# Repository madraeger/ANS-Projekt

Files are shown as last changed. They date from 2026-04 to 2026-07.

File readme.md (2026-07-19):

# FM-VCO

Dieses Repository enthält die Entwicklung, Simulation und praktische Umsetzung eines spannungsgesteuerten Oszillators für einen Frequenzmodulator.

Der VCO wird in **KiCad** aufgebaut und mit **ngspice** simuliert. Anschließend soll die Schaltung auf einer Platine umgesetzt und messtechnisch untersucht werden.

## Kundenanforderungen

Für den Frequenzmodulator wurden folgende Anforderungen vorgegeben:

- Mittenfrequenz von **5,5 MHz**
- Eingangssignal von **0 V**
- lineare Frequenzänderung von **±0,5 MHz**
- nutzbarer Frequenzbereich von **5 MHz bis 6 MHz**
- möglichst geringe nichtlineare Verzerrungen
- robuste und übersichtliche Platine für den Einsatz im Unterricht
- Verwendung möglichst großer und gut handhabbarer Bauteile
- integrierter Spannungsteiler zur Einstellung des Arbeitspunktes
- Ein- und Ausgang über BNC-Buchsen
- Ausgangswiderstand von **50 Ω**
- Korrektur einer Frequenzdrift über eine einstellbare Gleichspannung
- Aufnahme der Frequenzkennlinie mithilfe einer Gleichspannung
- möglichst kurzschlusssicherer Ausgang

## Grundlagen und Aufbau des VCOs

### Vom Schwingkreis zum Oszillator

Die Grundlage des VCOs bildet ein LC-Schwingkreis aus Induktivitäten und Kapazitäten. Im Schwingkreis wird Energie periodisch zwischen dem magnetischen Feld der Induktivitäten und dem elektrischen Feld der Kapazitäten ausgetauscht.

Die Resonanzfrequenz kann näherungsweise mit

$$
f_0 \approx \frac{1}{2\pi\sqrt{L_\text{}C_\text{}}}
$$

beschrieben werden.

Dabei sind:

- $L_\text{}$ die wirksame Induktivität des Schwingkreises
- $C_\text{}$ die gesamte wirksame Kapazität einschließlich parasitärer Kapazitäten

Ein realer LC-Schwingkreis besitzt Verluste, beispielsweise durch die Innenwiderstände der Induktivitäten, Leiterbahnen und angeschlossene Messgeräte. Ohne zusätzliche Energiezufuhr würde die Schwingung deshalb mit der Zeit abklingen.

Damit eine dauerhafte Schwingung entsteht, muss eine aktive Schaltung die Verluste des Schwingkreises ausgleichen. Dazu wird ein Teil des Ausgangssignals phasenrichtig zurückgeführt und verstärkt. Beim Einschalten reichen bereits kleine Störungen und das elektrische Rauschen aus, um eine Schwingung anzuregen. Die Frequenzanteile in der Nähe der Resonanzfrequenz werden anschließend durch die Rückkopplung verstärkt.

Für das Anschwingen muss die Schleifenverstärkung zunächst ausreichend groß sein. Im eingeschwungenen Zustand stellt sich die Amplitude so ein, dass die zugeführte Energie den Verlusten des Schwingkreises entspricht.

### Aufbau des VCOs

Der verwendete VCO besteht grundsätzlich aus einem differentiellen LC-Schwingkreis, einem gekreuzt gekoppelten MOSFET-Paar und einer Stromquelle.

<p align="center">
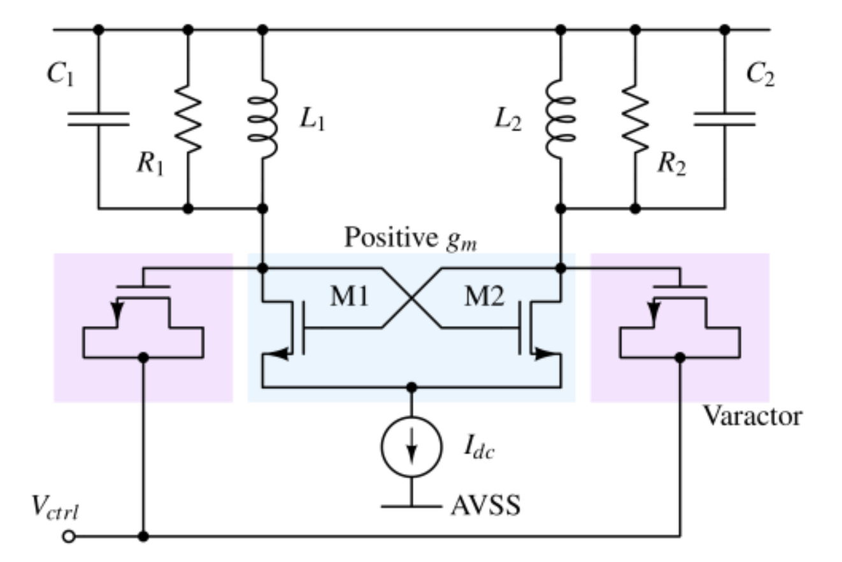
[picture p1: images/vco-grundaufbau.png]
Grundaufbau eines differentiellen LC-VCOs mit Cross-Coupled-MOSFETs
  
</p>

<p align="center">
  <em>
    Vereinfachter Aufbau eines differentiellen LC-VCOs.
    Quelle:
    <a href="https://analogcircuitdesign.com/voltage-controlled-oscillator/">
      Analog Circuit Design
    </a>
  </em>
</p>

Der VCO setzt sich aus folgenden Funktionsgruppen zusammen:

| Funktionsgruppe | Bauteile der Prinzipschaltung | Bauteile der aktuellen Schaltung | Aufgabe |
|---|---|---|---|
| LC-Schwingkreis | `L1`, `L2`, `C1`, `C2` sowie die Verlustwiderstände `R1`, `R2` | `L1`, `L2`, `D1`, `D2` | Festlegung der Resonanzfrequenz |
| Cross-Coupled-Paar | `M1`, `M2` | `Q1`, `Q2` | Ausgleich der Schwingkreisverluste und Aufrechterhaltung der Schwingung |
| Frequenzabstimmung | Varaktordioden und Steuerspannung `Vctrl` | `D1`, `D2` und Abstimmspannung `Vtune` | Veränderung der wirksamen Kapazität und damit der Ausgangsfrequenz |
| Stromquelle | ideale Stromquelle `Idc` | `Q3`, `Q4`, `R4` | Einstellung und Begrenzung des Arbeitspunktstroms |
| Ausgang | einer der beiden Schwingkreisknoten | rechter Schwingkreisknoten | Ausgabe des hochfrequenten Signals |

In der Prinzipschaltung werden die Verluste des LC-Schwingkreises durch die Parallelwiderstände `R1` und `R2` dargestellt. In der realen Schaltung entstehen diese Verluste bereits durch die Innenwiderstände der Spulen, die Varaktordioden, die MOSFETs und die Leiterbahnen. Deshalb wurden keine zusätzlichen Widerstände parallel zum Schwingkreis eingesetzt.

Die Kondensatoren `C1` und `C2` der Prinzipschaltung werden in der aktuellen Schaltung hauptsächlich durch die spannungsabhängigen Kapazitäten der Varaktordioden `D1` und `D2` ersetzt.

Der LC-Schwingkreis bestimmt die Ausgangsfrequenz. Das Cross-Coupled-Transistorpaar führt dem Schwingkreis die durch reale Verluste abgegebene Energie wieder zu. Die Varaktordioden ermöglichen die spannungsabhängige Frequenzeinstellung über `Vtune`.

Als Stromquelle wird ein einfacher NMOS-Stromspiegel verwendet. Dieser stellt den Arbeitspunktstrom für das Cross-Coupled-Transistorpaar bereit.

Die einzelnen Funktionsgruppen werden in den folgenden Abschnitten genauer beschrieben.
### Cross-Coupled-Transistorpaar

Die MOSFETs `Q1` und `Q2` sind über Kreuz miteinander gekoppelt. Das Gate eines Transistors ist jeweils mit dem Drain des anderen Transistors verbunden.

Die beiden Schwingkreisknoten schwingen dadurch näherungsweise gegenphasig. Steigt die Spannung an einem Knoten an, fällt sie am anderen Knoten ab.

Das Transistorpaar erzeugt im Schwingkreis einen negativen differentiellen Widerstand. Dieser wirkt den realen Verlustwiderständen des Schwingkreises entgegen. Sind die Verluste ausreichend kompensiert, kann die Schwingung dauerhaft bestehen bleiben.

### Spannungsabhängige Frequenzabstimmung

Damit aus dem LC-Oszillator ein spannungsgesteuerter Oszillator wird, werden die festen Kapazitäten durch Varaktordioden ersetzt.

Eine Varaktordiode wird in Sperrrichtung betrieben und verhält sich dabei wie ein spannungsabhängiger Kondensator. Die Abstimmspannung `Vtune` verändert die Sperrspannung und damit die Kapazität der Dioden.

Dadurch verändert sich die wirksame Kapazität des Schwingkreises:

$$
V_\text{tune}
\longrightarrow
C_\text{Varaktor}
\longrightarrow
f_\text{out}
$$

In der aktuellen Schaltung nimmt die gemessene Ausgangsfrequenz mit zunehmender Spannung `Vtune` ab. Die genaue Richtung der Frequenzänderung hängt von der Verschaltung der Varaktordioden und den Spannungsverhältnissen innerhalb des Schwingkreises ab.

Für einen möglichst verzerrungsarmen Frequenzmodulator sollte der Zusammenhang zwischen Abstimmspannung und Ausgangsfrequenz im verwendeten Arbeitsbereich möglichst linear sein:

$$
f_\text{out}
\approx
f_\text{Mitte}
+
K_\text{VCO}\cdot\left(V_\text{tune}-V_\text{Mitte}\right)
$$

Dabei beschreibt $K_\text{VCO}$ die Empfindlichkeit des VCOs und wird beispielsweise in `MHz/V` angegeben.

### NMOS-Stromspiegel

Die Stromquelle des VCOs wird als einfacher NMOS-Stromspiegel ausgeführt.

<p align="center">
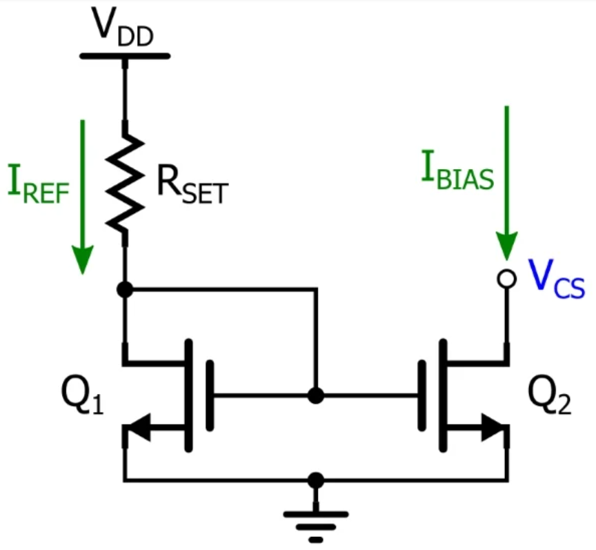
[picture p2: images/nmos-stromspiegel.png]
Einfacher NMOS-Stromspiegel mit Referenzwiderstand
  
</p>

<p align="center">
  <em>
    Prinzip eines einfachen NMOS-Stromspiegels.
    Quelle:
    <a href="https://www.allaboutcircuits.com/technical-articles/the-basic-mosfet-constant-current-source/">
      All About Circuits
    </a>
  </em>
</p>

Der Stromspiegel besteht in der aktuellen Schaltung aus den MOSFETs `Q3` und `Q4` sowie dem Widerstand `R4`.

Bei `Q4` sind Gate und Drain miteinander verbunden. Der Transistor ist damit als Referenztransistor beschaltet. Über den Widerstand `R4` stellt sich ein Referenzstrom ein.

Da die Gates von `Q3` und `Q4` miteinander verbunden sind, liegt an beiden MOSFETs näherungsweise dieselbe Gate-Source-Spannung an. Dadurch übernimmt `Q3` näherungsweise den Strom des Referenzzweigs und stellt den Arbeitspunktstrom für das Cross-Coupled-Transistorpaar bereit.

Die Bauteile der Prinzipschaltung entsprechen in der aktuellen VCO-Schaltung folgenden Bauteilen:

| Prinzipschaltung | Aktuelle Schaltung |
|---|---|
| Referenztransistor `Q1` | `Q4` |
| Ausgangstransistor `Q2` | `Q3` |
| Einstellwiderstand `RSET` | `R4` |
| Referenzstrom `IREF` | Strom durch `R4` und `Q4` |
| Ausgangsstrom `IBIAS` | Arbeitspunktstrom für `Q1` und `Q2` |

Der Referenzstrom kann vereinfacht mit folgender Gleichung abgeschätzt werden:

$$
I_\text{REF}
\approx
\frac{V_\text{DD}-V_\text{GS}}{R_4}
$$

Diese Gleichung ist nur eine Näherung, da die Gate-Source-Spannung `VGS` vom verwendeten MOSFET, vom Strom und von der Temperatur abhängt.

Der Stromspiegel stabilisiert damit den Arbeitspunkt der Schaltung, stellt jedoch keine vollständige automatische Regelung der Ausgangsamplitude dar.

## Verwendete Bauteile

Für den aktuellen Aufbau werden unter anderem folgende Bauteile verwendet:

| Bezeichnung | Bauteil | Funktion | SPICE-Modell / Bibliothek | Datenblatt |
|---|---|---|---|---|
| Q1, Q2 | [`BS170`](https://www.onsemi.com/download/data-sheet/pdf/mmbf170-d.pdf) | Cross-Coupled-Transistorpaar | `elk.lib` |  |
| Q3, Q4 | [`BS170`](https://www.onsemi.com/download/data-sheet/pdf/mmbf170-d.pdf) | NMOS-Stromspiegel | `elk.lib` |  |
| D1, D2 | [`1SV149`](https://www.radiomuseum.co.uk/filter/1SV149.pdf) | Varaktordioden zur Frequenzabstimmung | `BB112.lib` beziehungsweise eigenes `1SV149`-Modell |  |
| L1, L2 | 3,3 µH | Induktiver Teil des Schwingkreises | Standardmodell aus `spice.lib` | – |
| R4 | 51 kΩ | Einstellung des Referenzstroms im realen Aufbau | Standardmodell aus `spice.lib` | – |

Für die MOSFETs wird das Modell des `BS170` aus der Bibliothek `elk.lib` verwendet. Die passiven Bauteile greifen auf die Standardmodelle aus `spice.lib` zurück.

Für die Varaktordioden wurde zunächst das Modell aus `BB112.lib` verwendet, da damit in der Simulation eine deutliche Frequenzänderung erreicht werden konnte. Alternativ wird ein eigenes Modell für die `1SV149` eingesetzt. Das Modell aus `BB112.lib` entspricht dabei nicht exakt der real verbauten `1SV149`, sondern dient lediglich als Näherung ihres kapazitätsabhängigen Verhaltens.

## Aktueller Stand

Der VCO wurde sowohl in **SPICE simuliert** als auch **praktisch aufgebaut**. Der geforderte nutzbare Frequenzbereich von ungefähr **5 MHz bis 6 MHz** wird bereits erreicht.

Die Ausgangsfrequenz wird über die Abstimmspannung `Vtune` eingestellt. Mit steigender Abstimmspannung sinkt die Ausgangsfrequenz. Die aufgenommenen Messwerte zeigen dabei einen nahezu linearen Zusammenhang zwischen `Vtune` und der Ausgangsfrequenz.

### Gemessene f/V-Kennlinie

Die Kennlinie wurde aufgenommen, indem die Gleichspannung `Vtune` schrittweise verändert und die jeweilige Ausgangsfrequenz gemessen wurde.

| `Vtune` in V | Frequenz in MHz |
|---:|---:|
| 5,33 | 6,00 |
| 5,50 | 5,90 |
| 5,63 | 5,83 |
| 5,82 | 5,69 |
| 5,92 | 5,61 |
| 6,06 | 5,52 |
| 6,24 | 5,42 |
| 6,36 | 5,33 |
| 6,54 | 5,21 |
| 6,70 | 5,11 |
| 6,89 | 5,01 |

<p align="center">
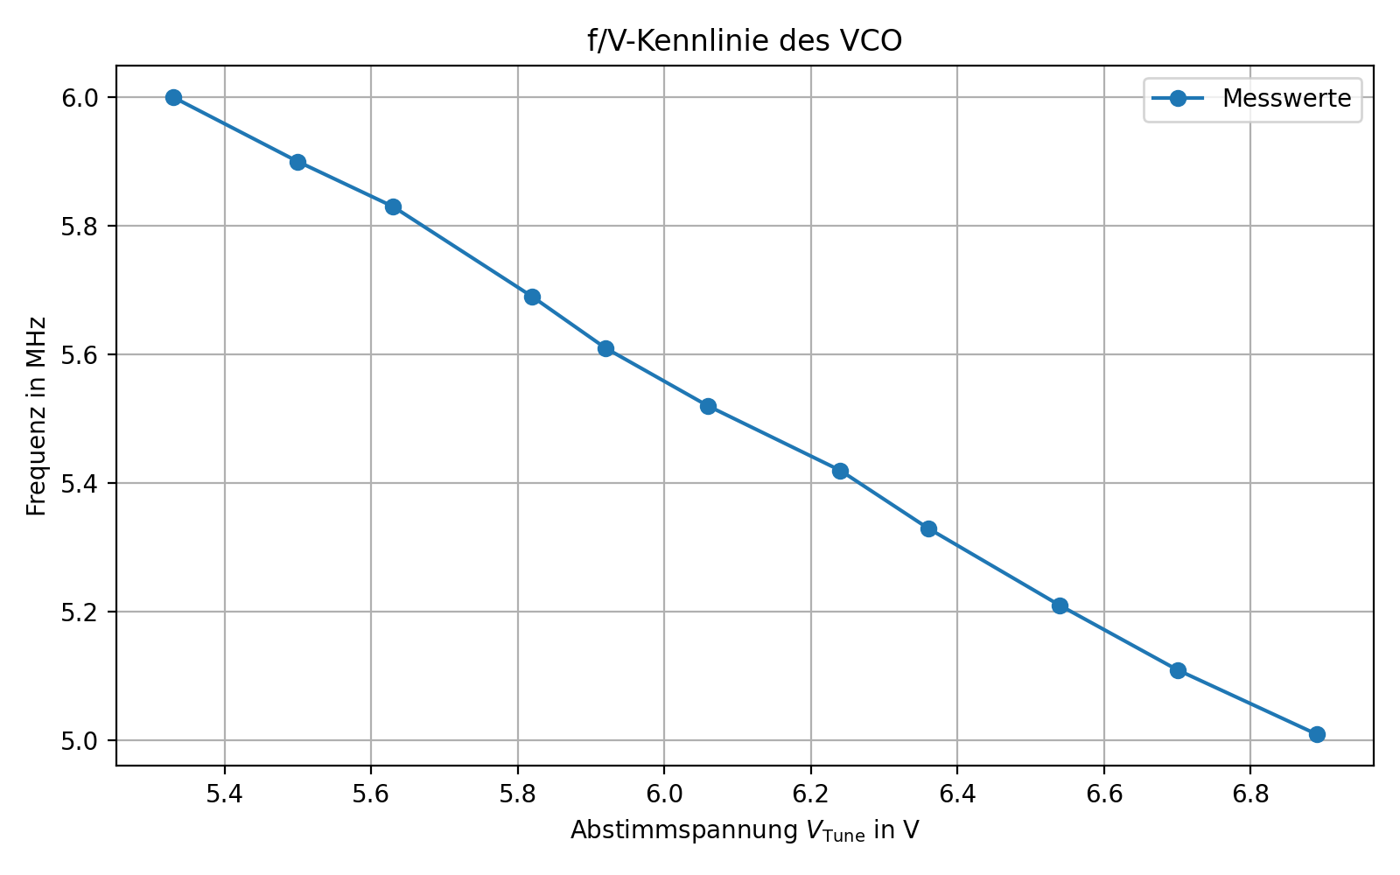
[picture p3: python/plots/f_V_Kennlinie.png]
Gemessene f/V-Kennlinie des VCOs
  
</p>

<p align="center">
  <em>Gemessene Ausgangsfrequenz in Abhängigkeit von der Abstimmspannung Vtune</em>
</p>

Die VCO-Empfindlichkeit beträgt näherungsweise:

$$
K_\text{VCO}
\approx
-0{,}650\,
\frac{\text{MHz}}{\text{V}}
$$

Das negative Vorzeichen bedeutet, dass die Ausgangsfrequenz mit steigender Abstimmspannung abnimmt.

Die Mittenfrequenz von ungefähr **5,5 MHz** wird bei einer Abstimmspannung von etwa **6,1 V** erreicht.

Für den gesamten Frequenzbereich von ungefähr **5 MHz bis 6 MHz** wird eine Spannungsänderung von etwa

$$
\Delta V_\text{tune} = 6{,}89\,\text{V} - 5{,}33\,\text{V} = 1{,}56\,\text{V}
$$

benötigt.

Bezogen auf den Arbeitspunkt bei ungefähr **6,1 V** entspricht dies einem benötigten Spannungshub von ungefähr:

$$
V_\text{tune}
\approx
6{,}1\,\text{V}
\pm
0{,}78\,\text{V}
$$

Der ursprünglich vorgesehene Eingangsspannungsbereich von ungefähr **±0,5 V** reicht daher ohne eine zusätzliche Anpassung nicht für den vollständigen Frequenzbereich aus.

### Gemessene Ausgangssignale

Die folgende Abbildunge zeigt die letzten zwei Perioden des mit dem Oszilloskop aufgenommenen Ausgangssignals.

<p align="center">
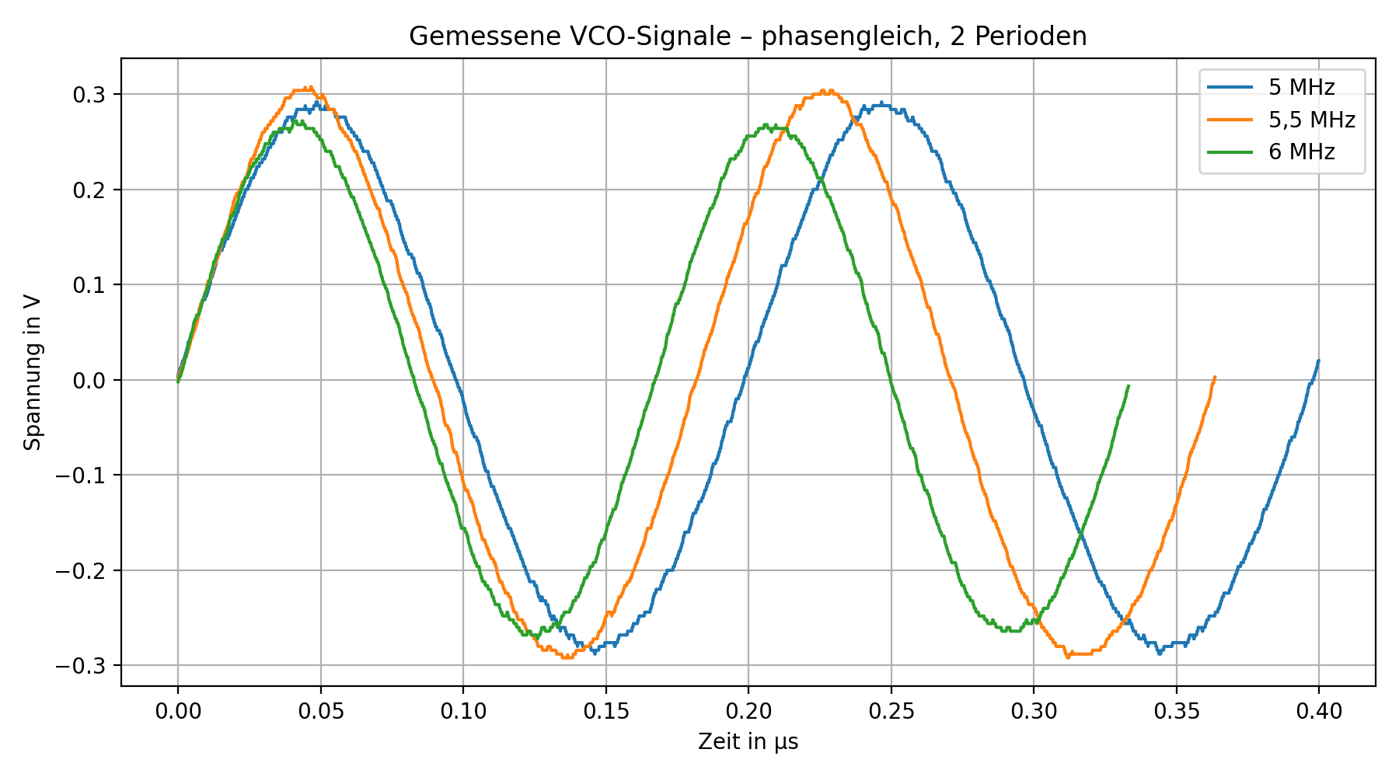
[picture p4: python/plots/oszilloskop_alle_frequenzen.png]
Oszilloskopmessung des Ausgangssignals bei 5 MHz
  
</p>

<p align="center">
  <em>Gemessenes Ausgangssignal bei 5 - 6 MHz</em>
</p>

Die gemessenen Signale besitzen über den untersuchten Frequenzbereich eine weitgehend sinusförmige Signalform.

Die Ausgangsamplitude ist bei **5 MHz** und **5,5 MHz** ähnlich groß. In Richtung **6 MHz** nimmt die Amplitude jedoch sichtbar ab. Die Ursache dafür muss im weiteren Projektverlauf noch untersucht werden.

### Simulation und Vergleich

Für die Frequenzen **5 MHz**, **5,5 MHz** und **6 MHz** wurden die simulierten Ausgangssignale mit den Oszilloskopmessungen verglichen.

<details>
  <summary><strong>Vergleich bei 5 MHz anzeigen</strong></summary>

  #### Vergleich bei 5 MHz

  <p align="center">
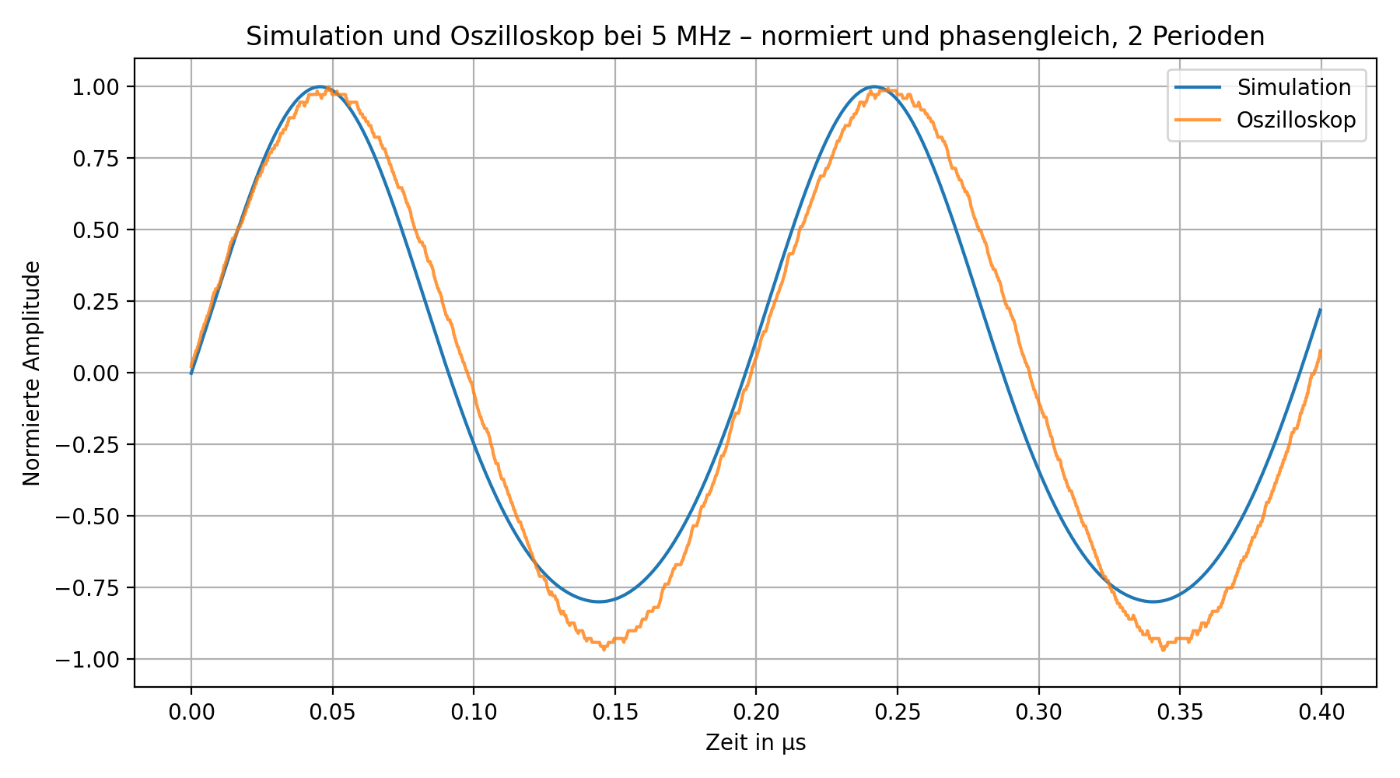
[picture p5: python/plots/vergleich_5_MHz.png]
Vergleich zwischen Simulation und Messung bei 5 MHz
    
  </p>
</details>

<details>
  <summary><strong>Vergleich bei 5,5 MHz anzeigen</strong></summary>

  #### Vergleich bei 5,5 MHz

  <p align="center">
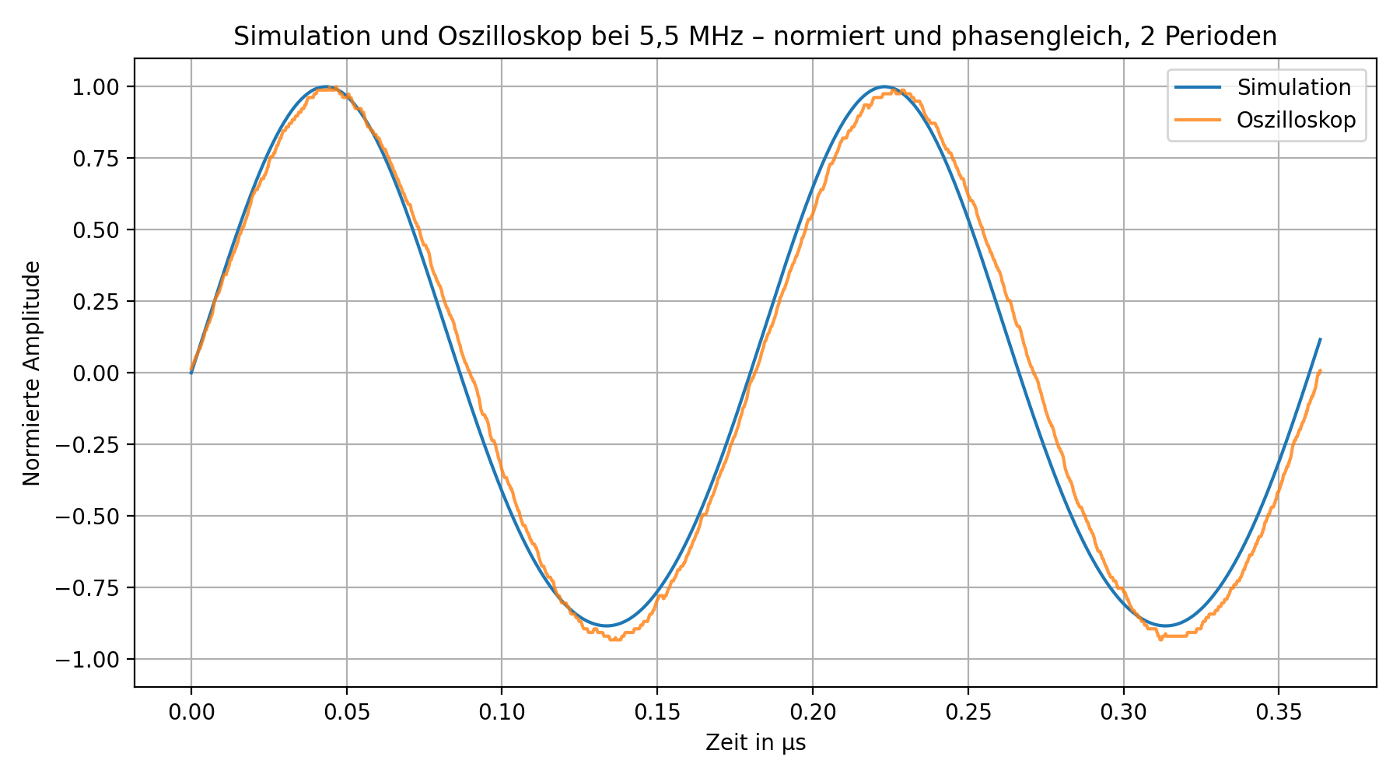
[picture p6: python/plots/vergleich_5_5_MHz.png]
Vergleich zwischen Simulation und Messung bei 5,5 MHz
    
  </p>
</details>

<details>
  <summary><strong>Vergleich bei 6 MHz anzeigen</strong></summary>

  #### Vergleich bei 6 MHz

  <p align="center">
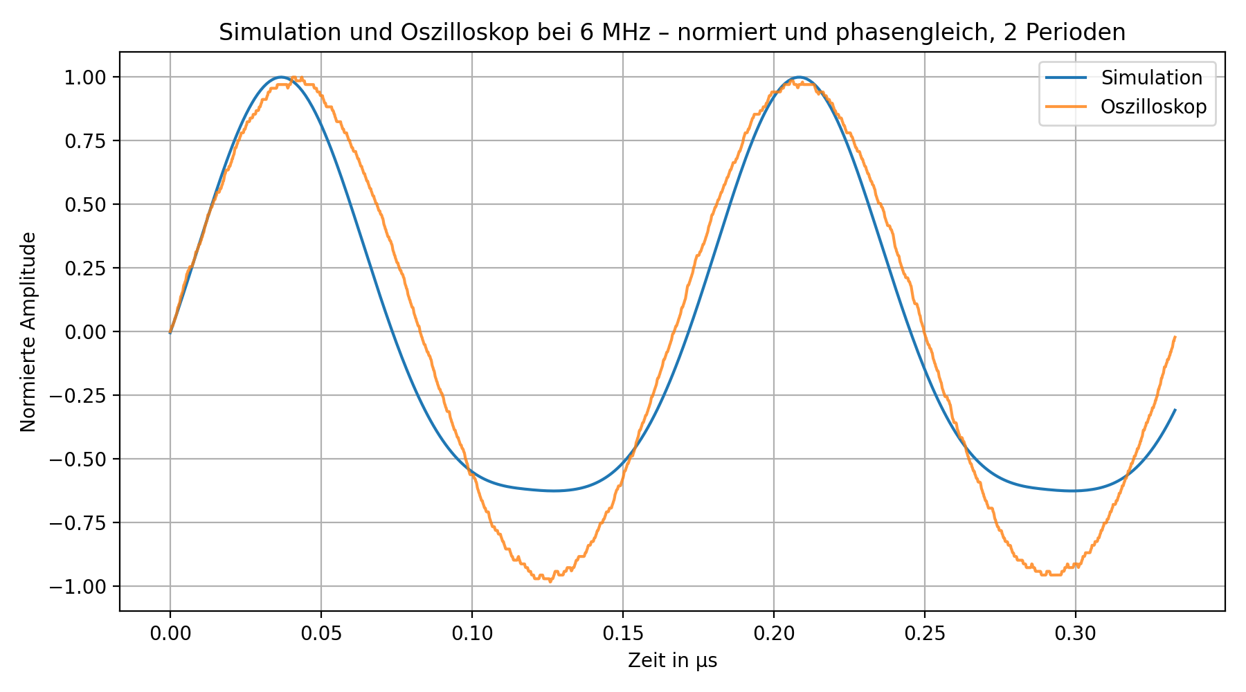
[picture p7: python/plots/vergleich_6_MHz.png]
Vergleich zwischen Simulation und Messung bei 6 MHz
    
  </p>
</details>

Die normierten Vergleichsplots zeigen, dass Simulation und Messung grundsätzlich eine ähnliche periodische Signalform besitzen.

Die Simulation beschreibt damit das grundsätzliche Schwingverhalten, bildet den realen Arbeitspunkt und die tatsächliche Ausgangsamplitude jedoch nur eingeschränkt ab.

### Unterschiede zwischen Simulation und realem Aufbau

Für den NMOS-Stromspiegel werden in der Simulation und im realen Aufbau unterschiedliche Widerstandswerte benötigt.

Im realen Aufbau wird für `R4` ein Widerstand von **51 kΩ** verwendet. Bei größeren Widerständen ist der Strom zu gering, sodass der Oszillator nicht zuverlässig anschwingt.

In der SPICE-Simulation wird dagegen ein größerer Widerstand benötigt, da kleinere Widerstandswerte dort zu stärkeren Verzerrungen des Ausgangssignals führen.

Zusätzlich wurden im realen Aufbau Kondensatoren parallel zur Spannungsversorgung eingesetzt. Diese dienen als Abblock- und Stützkondensatoren und reduzieren hochfrequente Störungen sowie kurzzeitige Spannungsschwankungen.

### Platinenlayout

Eine erste Platine wurde bereits in KiCad erstellt. Das Layout muss jedoch noch an den aktuellen Schaltungsstand angepasst und weiter optimiert werden.

Besonders berücksichtigt werden müssen:

- Platzierung der Abblockkondensatoren nahe an den MOSFETs
- Ein- und Ausgangsanpassung

## Noch nicht vollständig erfüllte Anforderungen

Der geforderte Frequenzbereich von ungefähr **5 MHz bis 6 MHz** und die Mittenfrequenz von ungefähr **5,5 MHz** werden bereits erreicht. Auch die Frequenzkennlinie wurde mithilfe einer veränderlichen Gleichspannung aufgenommen und zeigt im untersuchten Bereich einen nahezu linearen Verlauf.

Folgende Kundenanforderungen sind noch nicht vollständig erfüllt:

- Anpassung des Eingangs von **0 V**
- Umsetzung einer Frequenzänderung von ungefähr **±0,5 MHz** bei einem Eingangssignal von **±0,5 V**
- weitere Verringerung beziehungsweise genaue Bewertung der nichtlinearen Verzerrungen
- Anpassung und Optimierung des bereits erstellten Platinenlayouts
- Realisierung eines Ausgangswiderstands von **50 Ω**
- Umsetzung und Prüfung der Korrektur einer Frequenzdrift über eine einstellbare Gleichspannung
- möglichst kurzschlusssichere Auslegung des Ausgangs
- Aufbau und Prüfung der endgültigen Platine

## Verwendete Software

Für die Entwicklung, Simulation und Versionsverwaltung werden folgende Programme verwendet:

| Software | Verwendung | Download |
|---|---|---|
| KiCad | Erstellung des Schaltplans und des Platinenlayouts |  |
| ngspice | Simulation der Schaltung und Untersuchung des VCO-Verhaltens |  |
| Git | Lokale Versionsverwaltung des Projekts |  |
| GitHub | Speicherung und gemeinsame Bearbeitung des Repositorys |  |

KiCad verwendet für die integrierte SPICE-Simulation ngspice. Abhängig von der KiCad-Installation kann ngspice daher bereits enthalten sein.

## Projekt öffnen

Das Repository kann mit folgendem Befehl geklont werden:

```bash
git clone <URL-DES-REPOSITORY>
```

Der aktuelle Stand des KiCad-Projekts befindet sich im folgenden Unterordner:

```text
kicad/FM-ELK_LC-VCO-V3
```

Anschließend kann die darin enthaltene `.kicad_pro`-Datei mit KiCad geöffnet werden.

Vor der Simulation sollte überprüft werden, ob:

- alle Symbolbibliotheken vorhanden sind
- alle Footprints korrekt zugeordnet sind
- das SPICE-Modell der `1SV149` eingebunden ist
- die Modellpfade in KiCad korrekt eingestellt sind

## Projektteam

<p>
  <a href="https://github.com/madraeger">
    
  </a>
  <a href="https://github.com/ethaniellingkoenig">
    
  </a>
</p>

## Literaturverzeichnis

Die folgenden Quellen wurden für die Grundlagen und die Entwicklung der Schaltung verwendet:

1. [Analog Circuit Design: Voltage Controlled Oscillator – VCO Basics, Operation, Tuning and Use in Communication Circuits](https://analogcircuitdesign.com/voltage-controlled-oscillator/)  
   Grundlagen zu spannungsgesteuerten Oszillatoren, LC-VCOs, Varaktordioden und VCO-Kennlinien.

2. [Electronics Tutorials: LC Oscillator Tutorial and Tuned LC Oscillator Basics](https://www.electronics-tutorials.ws/oscillator/oscillators.html)  
   Grundlagen zu LC-Schwingkreisen, Rückkopplung und den Bedingungen für eine dauerhafte Schwingung.

3. [ElektronikTutor: Frequenzmodulation](https://www.elektroniktutor.de/signalkunde/fm.html)  
   Grundlagen zur Frequenzmodulation, zum Frequenzhub, zum Modulationsindex und zur Bandbreite eines FM-Signals.

4. [All About Circuits: The Basic MOSFET Constant-Current Source](https://www.allaboutcircuits.com/technical-articles/the-basic-mosfet-constant-current-source/)  
   Grundlagen zur MOSFET-Stromquelle und zum Stromspiegel.

Alle Internetquellen wurden zuletzt am **18. Juli 2026** abgerufen.

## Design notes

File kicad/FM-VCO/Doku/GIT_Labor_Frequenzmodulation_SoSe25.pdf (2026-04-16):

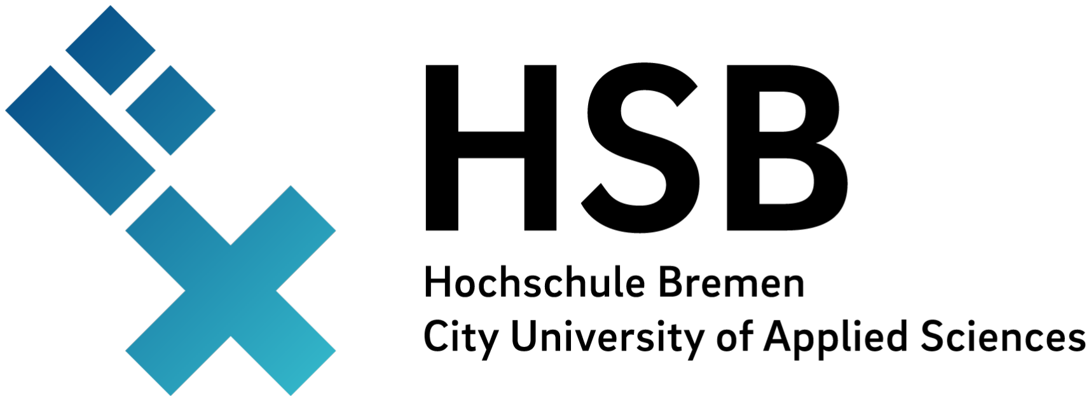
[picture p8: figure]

# Grundlagen der Informationstechnik -Labor-

## Versuch GIT-L 3 Frequenzmodulation

### Prof. Dr.-Ing. Mario Goldenbaum Fakultät für Elektrotechnik und Informatik Hochschule Bremen

Versuch GIT-L 3

## 1 Einleitung

Gegenstand dieses Laborversuchs ist die messtechnische Auseinandersetzung mit der aus der Vorlesung bekannten Frequenzmodulation (FM) bzw. der Winkelmodulation im weiteren Sinne. Mit Hilfe der FM kann ein informationstragendes Signal durch Änderung der Momentanfrequenz eines sinusförmigen Trägers in einen anderen Frequenzbereich umgesetzt werden. Eine Schaltung, die diesem Prinzip folgt und hier näher untersucht werden soll ist am Ende der Versuchsbeschreibung in den Abbildungen 1–3 dargestellt. Den wesentlichen Kern dieser Schaltung bildet ein spannungsgesteuerter Oszillator (LC-Schwingkreis), der mittels eines astabilen Multivibrators rhythmisch angefacht wird.

## 2 Versuchsvorbereitung

Für eine angemessene Vorbereitung auf die Versuchsdurchführung ist es erforderlich, dass Sie die Versuchsbeschreibung aufmerksam lesen und sich hinreichend mit der Funktionsweise der Schaltung in Abb. 1 vertraut machen. Darüber hinaus sollten Sie in der Lage sein, die folgenden Fragen zu beantworten bzw. entsprechende Begriffe zu erörtern.

- Was ist das grundlegende Prinzip der Frequenz- und der Phasenmodulation?
- Wie sehen winkelmodulierte Signale im Zeitbereich typischerweise aus?
- Wie ist der Modulationsindex m definiert und was beschreibt er?
- Wie lässt sich das Frequenzspektrum eines FM-Signals berechnen bei einem sinusförmigen Informationssignal?
- Wie lässt sich der Bandbreitebedarf eines FM-Signals abschätzen?
- Wie hängen die Frequenz- und die Phasenmodulation miteinander zusammen?
- Was versteht man unter Frequency Shift Keying (FSK)?

Fertigen Sie im Anschluss an die Versuchsdurchführung einen Laborbericht an, der neben den Antworten auf diese Fragen eine detaillierte Auseinandersetzung mit den Messaufgaben enthält, gefolgt von einer kritischen Beurteilung der erhaltenen Ergebnisse.

© Prof. Dr.-Ing. Mario Goldenbaum | ver25/1 | 1

Versuch GIT-L 3

## 3 Versuchsdurchführung

### 3.1 Statische Modulationskennlinie

In diesem Versuchsteil soll zunächst die Wirkungsweise der Modulatorschaltung aus Abb.1 näher untersucht werden, indem die Abhängigkeit zwischen dem Ausgang des Modulators (moduliertes Signal) und seinem Eingang (modulierendes Signal) messtechnisch erfasst, ausgewertet und beurteilt wird.

1.1 Ermitteln Sie messtechnisch die statische Modulationskennlinie ω = f(Ue), d.h. die Momentanfrequenz ω = ω(t) der modulierten Ausgangsspannung xFM(t) als Funktion des Augenblickswertes Ue des modulierenden Eingangssignals u(t). Führen Sie dafür den Augenblickswert in Form einer Gleichspannung an den DC-Eingang und variieren diese schrittweise mittels des auf der Platine befindlichen Drehpotentiometers im Bereich von −4 V bis +9 V. Messen Sie für jeden Augenblickswert die Momentanfrequenz am Ausgang des Modulators mit einem Frequenzzähler oder Oszilloskop.

1.2 Stellen Sie die Kennlinie dar und wählen einen Bereich, der Ihnen für einen ordnungsgemäßen Betrieb des Modulators sinnvoll erscheint.

### 3.2 Frequenzspektren harmonischer Modulationssignale

Die folgenden Messaufgaben dienen dazu das frequenzmodulierte Ausgangssignal xFM(t) im Frequenzbereich zu untersuchen und mit den Verläufen zu vergleichen, die man auf Grund theoretischer Überlegungen erwarten würde.

2.1 Für ein sinusförmiges Modulationssignal mit einer Frequenz f1 = 10 kHz sollen frequenzmodulierte Signale mit den Modulationsindizes m = 0,5, m = 2,4 und m = 10 realisiert werden. Bestimmen Sie dafür zunächst die benötigten Frequenzhübe ∆Ω (bzw. ∆F in Hz) und berechnen mit Hilfe der Kennlinie aus 1.1 die einzustellenden Signalamplituden.

Berechnen Sie nun unter Verwendung der in den Abbildungen 4 und 5 dargestellten Besselfunktionen erster Art ν-ter Ordnung für alle drei Fälle die Frequenzspektren. Anschließend bestimmen Sie die Frequenzspektren messtechnisch mit dem Spektrumanalysator. Vergleichen Sie die Messwerte mit Ihren Berechnungen und bestimmen den jeweiligen Bandbreitebedarf der Signale mit der Formel von Carson.

2.2 Wiederholen Sie die vorangegangene Messung für einen Modulationsindex von m = 2,4 bei einer Signalfrequenz von f1 = 20 kHz. Bestimmen Sie dafür die benötigte Signalamplitude des modulierenden Signals und vergleichen das Spektrum mit dem aus 2.1. Wie groß wäre die benötigte Amplitude, wenn es sich um eine Phasenmodulation handeln würde?

© Prof. Dr.-Ing. Mario Goldenbaum | ver25/1 | 2

Versuch GIT-L 3

2.3 Der Frequenzmodulator soll nun als Phasenmodulator betrieben werden. Welcher mathematischen Operation ist dafür das Eingangssignal vor der Einspeisung am Eingang zu unterziehen? Dimensionieren Sie eine entsprechende Schaltung, die diese Operation in einem Frequenzbereich von etwa 10 kHz−20 kHz realisiert. Erzeugen Sie nun mit der modifizierten Schaltung ein phasenmoduliertes Signal für f1 = 20 kHz und m = 2,4 und messen dessen Frequenzspektrum. Vergleichen Sie das Spektrum mit dem zuvor in 2.2 gemessenen Spektrum für die frequenzmodulierte Variante.

### 3.3 Frequenzspektren periodischer Modulationssignale

Im bisherigen Versuchsverlauf haben wir uns ausschließlich mit sinusförmigen Modulationssignalen beschäftigt. In diesem Versuchsteil sollen die Untersuchungen auf andere periodische Signalformen ausgedehnt werden.

3.1 Messen Sie das Frequenzspektrum eines Sinus-, eines Dreieck- und eines Rechtecksignals der Frequenz f1 = 10 kHz und einer Amplitude, die im Falle des Sinussignals zu einem Modulationsindex von m = 10 führt. Vergleichen Sie die Spektren miteinander.

3.2 Realisieren Sie mit einem Rechtecksignal der Frequenz f1 = 10 kHz eine Frequenzumtastung (FSK, Frequency Shift Keying). Bestimmen Sie mit Hilfe der unter 1.1 gemessenen statischen Modulationskennlinie die benötigten Signalamplituden für einen Modulationsindex von m = 0,5 (MSK, Minimum Shift Keying) sowie für m = 1. Wie lassen sich die Spektren erklären?

3.3 Für ein niederfrequentes Dreiecksignal (Wobbelsignal) soll das Spektrum in Abhängigkeit von der Wobbelfrequenz bei einem Wobbelhub von etwa 250 kHz gemessen werden. Messen Sie abschließend das Spektrum eines Sinussignals mit wachsender Signalfrequenz (f1 > 20 kHz), das jeweils zu einem Modulationsindex von m = 10 führt. Woher rühren die Abweichungen vom erwarteten Verlauf bei höheren Frequenzen?

© Prof. Dr.-Ing. Mario Goldenbaum | ver25/1 | 3

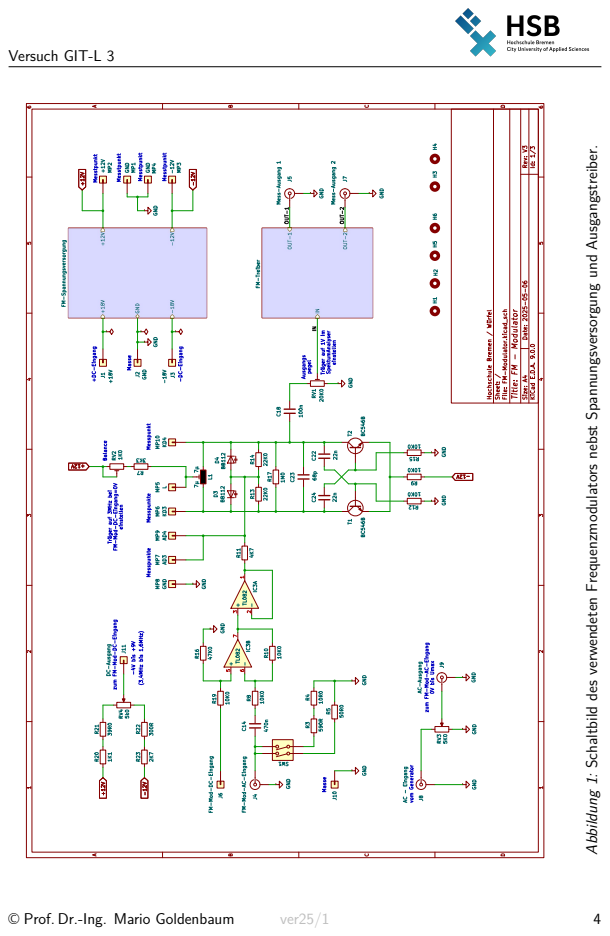
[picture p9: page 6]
Versuch GIT-L 3; © Prof. Dr.-Ing. Mario Goldenbaum; ver25/1

Abbildung 1: Schaltbild des verwendeten Frequenzmodulators nebst Spannungsversorgung und Ausgangstreiber.

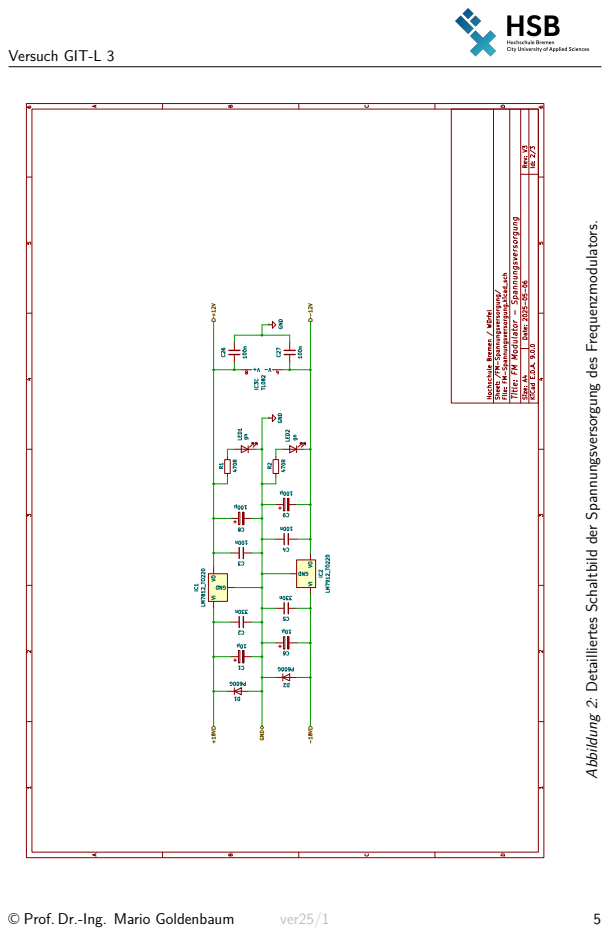
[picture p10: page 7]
Versuch GIT-L 3; © Prof. Dr.-Ing. Mario Goldenbaum; ver25/1

Abbildung 2: Detailliertes Schaltbild der Spannungsversorgung des Frequenzmodulators.

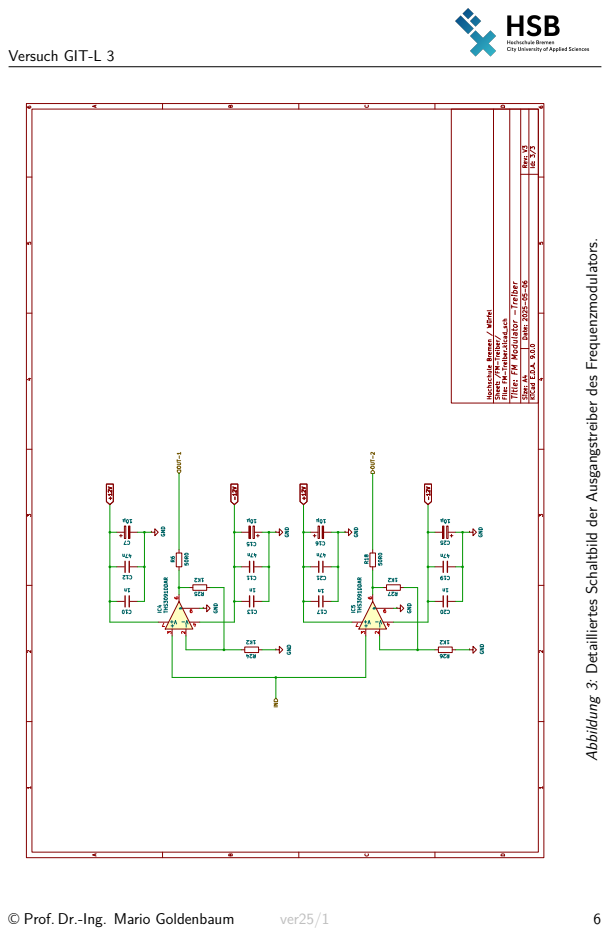
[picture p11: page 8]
Versuch GIT-L 3; © Prof. Dr.-Ing. Mario Goldenbaum; ver25/1

Abbildung 3: Detailliertes Schaltbild der Ausgangstreiber des Frequenzmodulators.

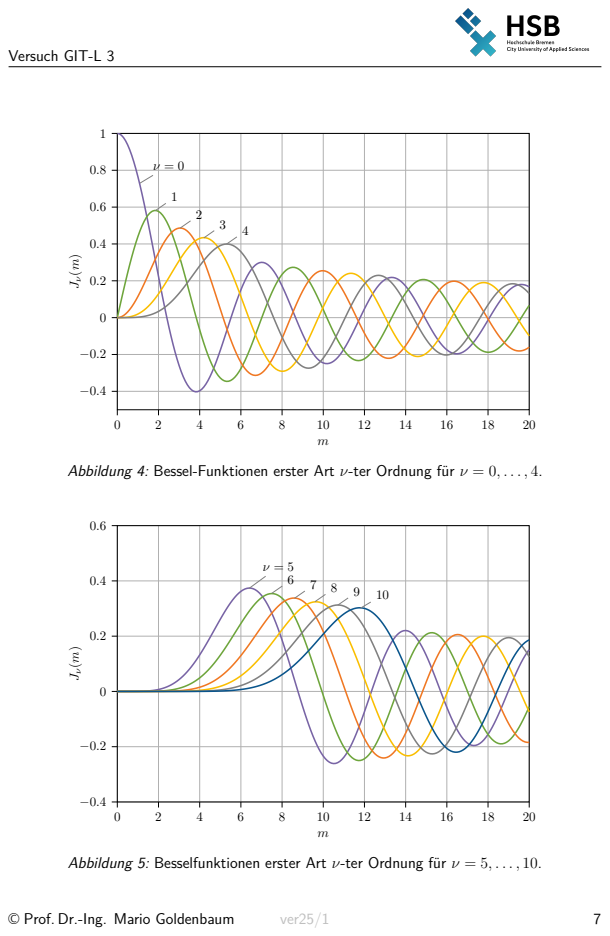
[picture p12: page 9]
Versuch GIT-L 3; © Prof. Dr.-Ing. Mario Goldenbaum; ver25/1

Abbildung 4: Bessel-Funktionen erster Art ν-ter Ordnung für ν = 0, . . . , 4.

Abbildung 5: Besselfunktionen erster Art ν-ter Ordnung für ν = 5, . . . , 10.

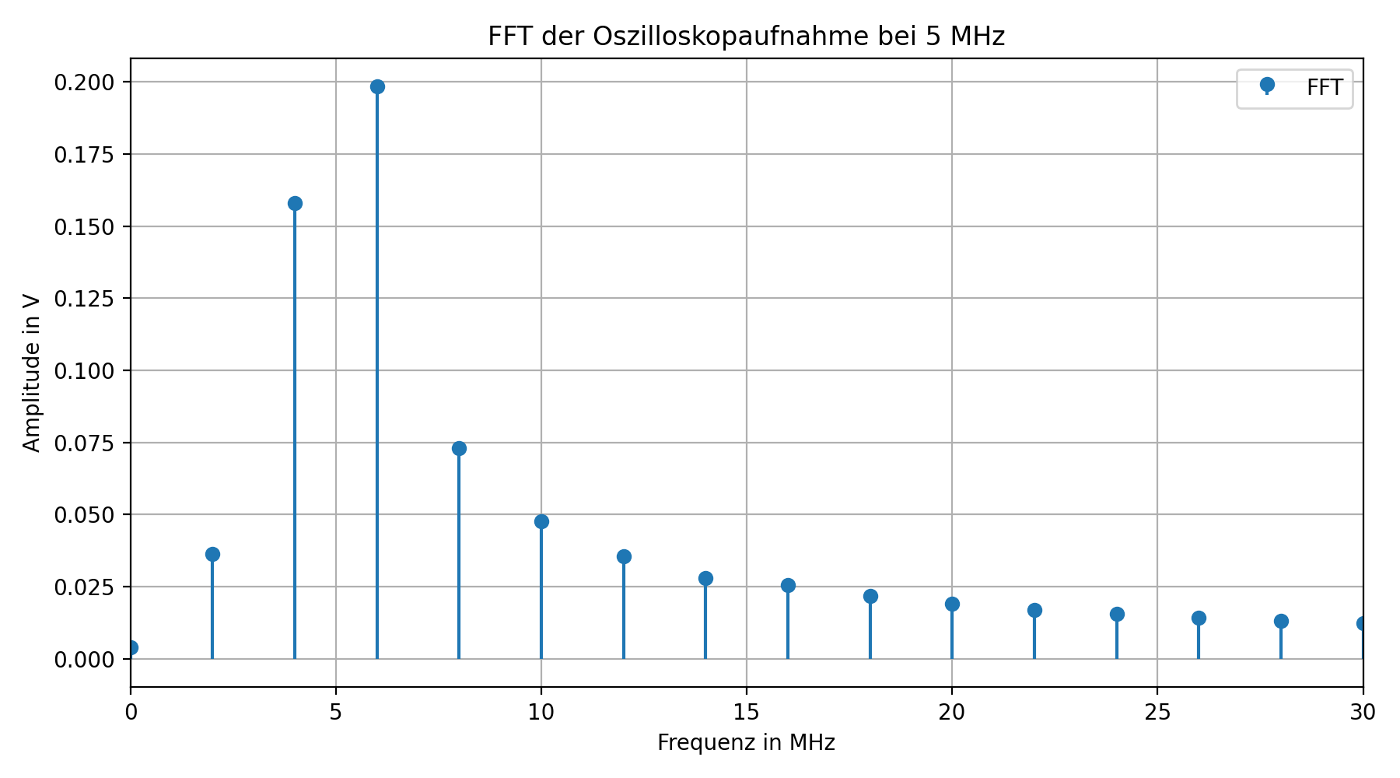
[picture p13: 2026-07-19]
python/plots/fft_5_MHz.png

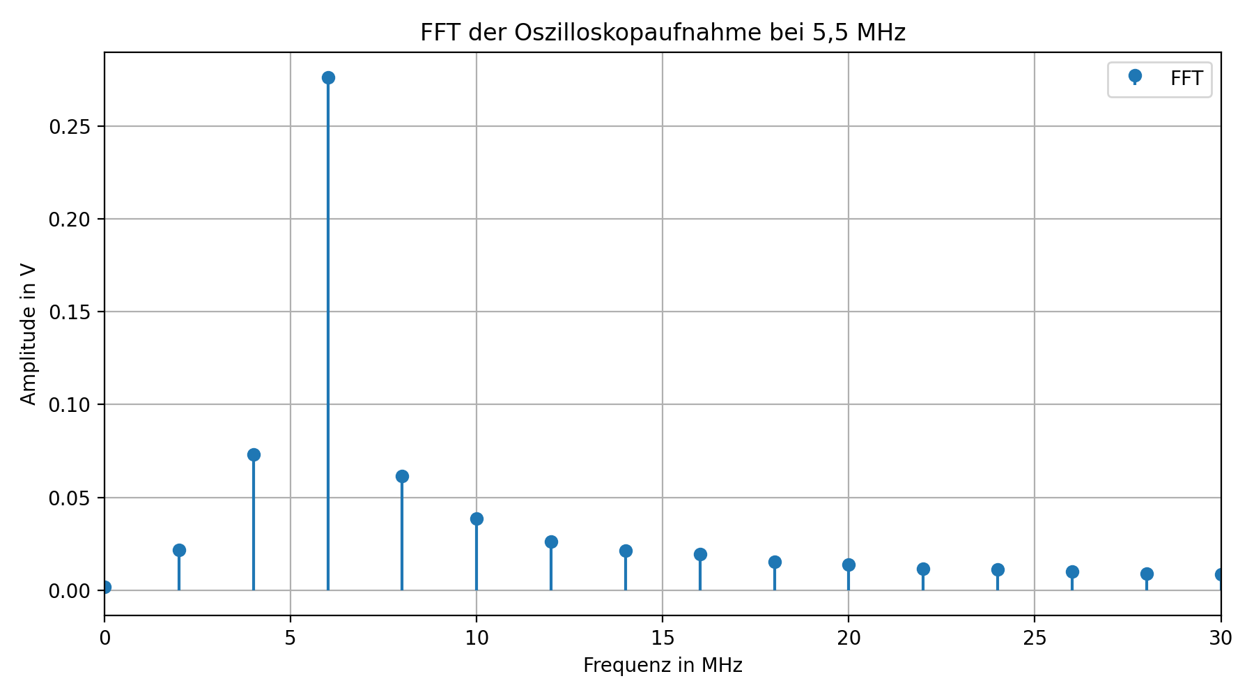
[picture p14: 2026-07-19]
python/plots/fft_5_5_MHz.png

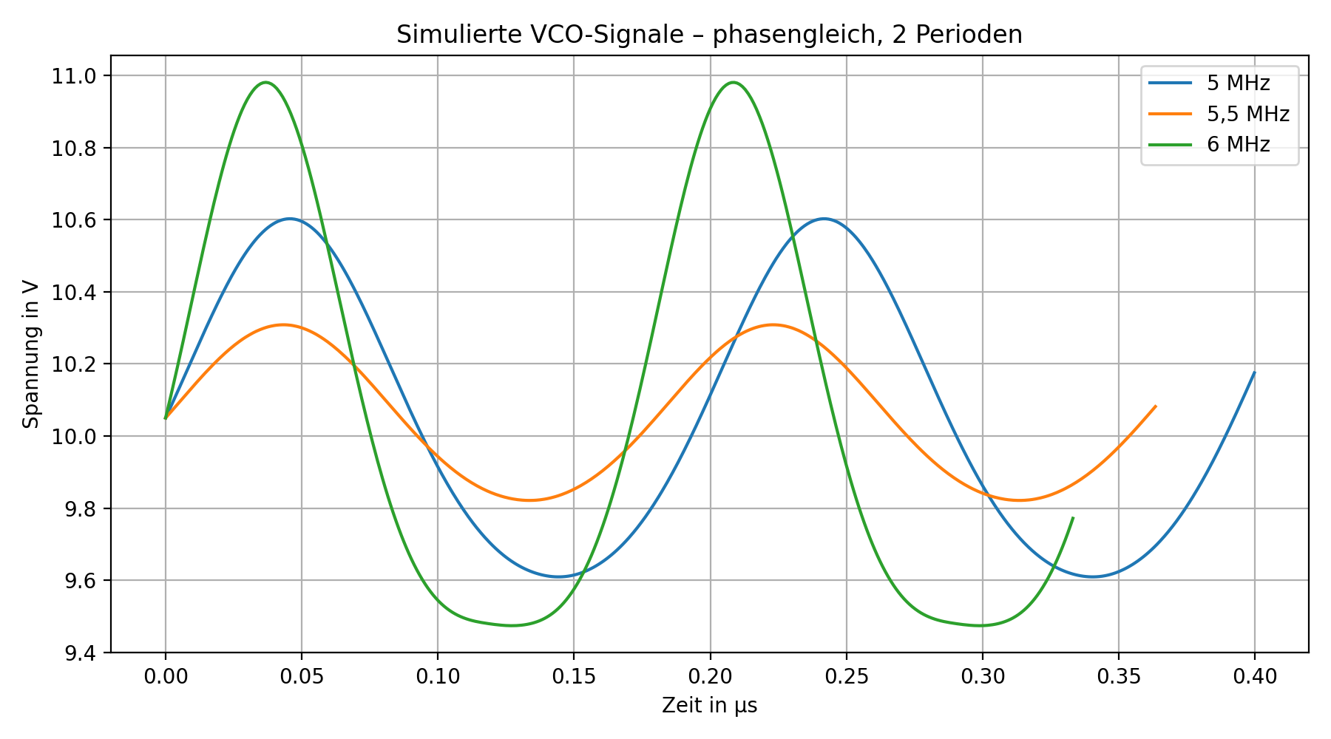
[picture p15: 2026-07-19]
python/plots/simulation_alle_frequenzen.png

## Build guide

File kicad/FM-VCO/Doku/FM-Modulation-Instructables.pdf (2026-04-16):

## FM Modulation/de-modulation Circuit

By brmarcum (https://www.instructables.com/member/brmarcum/) in Circuits (https://www.instructables.com/circuits/)Electronics (https://www.instructables.com/circuits/electronics/projects/)

## Introduction: FM Modulation/de-modulation Circuit

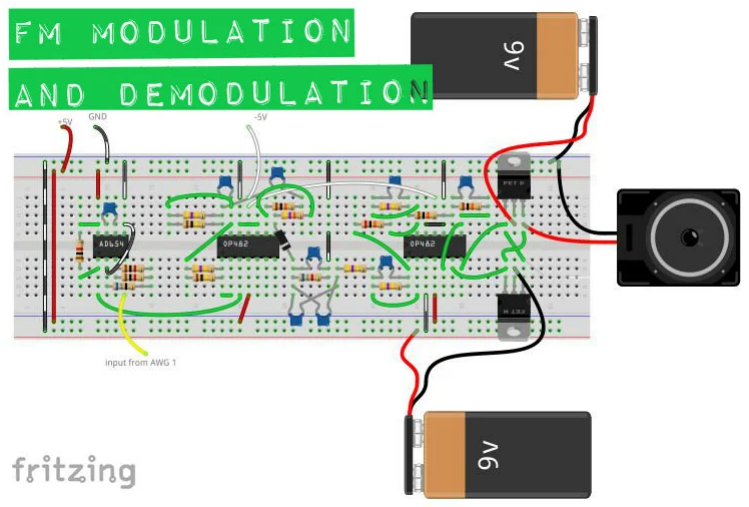
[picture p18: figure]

I got the idea for this circuit from one of my professors. That design wasn't meant for passing frequencies high enough to be able to pass an audio file, e.g. 500Hz+, so I built this by modifying the carrier and signal frequencies, using only the Digilent Analog Discovery (http://digilentinc.com/Products/Detail.cfm?NavPath=2,1040,1043&Prod=ANALOG-DISCOVERY) and the Analog Parts Kit. (http://digilentinc.com/Products/Detail.cfm?NavPath=2,1040,1066&Prod=APK) It should be noted that this circuit is primarily for educational purposes. Also note that there is no radio transmission here either. FM doesn't necessarily mean radio waves have to be involved.

Throughout this Instructable I will be going through some of the functions and features of the Analog Discovery, but it will not be an exhaustive tutorial.

## Step 1: Parts and Tools

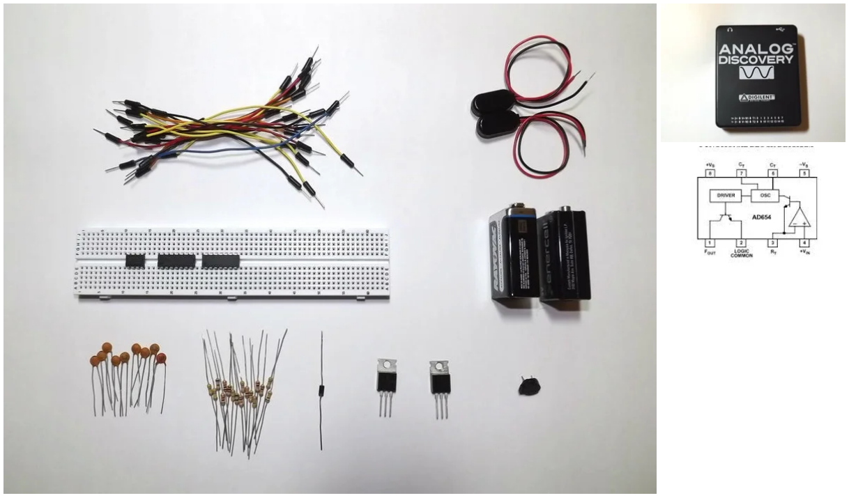
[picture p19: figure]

All of the parts listed below are provided in the Analog Starter Kit, (http://digilentinc.com/Products/Detail.cfm?NavPath=2,1040,1066&Prod=APK) except for the 9V batteries and clips. They should also be available through various online suppliers, local shops, or the salvage bin on your workbench.

The Parts:

- 2 OP482 quad op-amps (datasheet) (http://www.analog.com/static/imported-files/data_sheets/OP282_482.pdf)
- AD654 voltage to frequency converter (datasheet) (http://www.analog.com/static/imported-files/data_sheets/AD654.pdf)
- 9 ceramic capacitors: 2 - 39pF (39), 2 - 100pF (101), 2 - 1nF (102), 2 - 4.7nF (472), 1 - 10nF (103)
- 17 carbon film resistors: 1 - 68, 3 - 1k, 1 - 6.8k, 3 - 10k, 1 - 20k, 1 - 47k, 2 - 100k, 5 - 470k
- 1 1N4001 rectifier diode
- 1 speaker
- solderless breadboard
- jumper wires

(optional)

- 1 TIP31C NPN BJT
- 1 TIP32C PNP BJT
- 2 9V batteries with clips

The Tools:

- Digilent Analog Discovery (http://digilentinc.com/Products/Detail.cfm?NavPath=2,1040,1043&Prod=ANALOG-DISCOVERY)
- Waveforms (http://digilentinc.com/Products/Detail.cfm?NavPath=2,66,849&Prod=WAVEFORMS) software (free but required to run the Analog Discovery)
- short, free .wav (http://www.wavsource.com/) file download.

Pin-out diagrams are included for the OP482 quad op-amp and AD654 voltage to frequency converter, also called a voltage controlled oscillator or VCO.

## Step 2: Designing

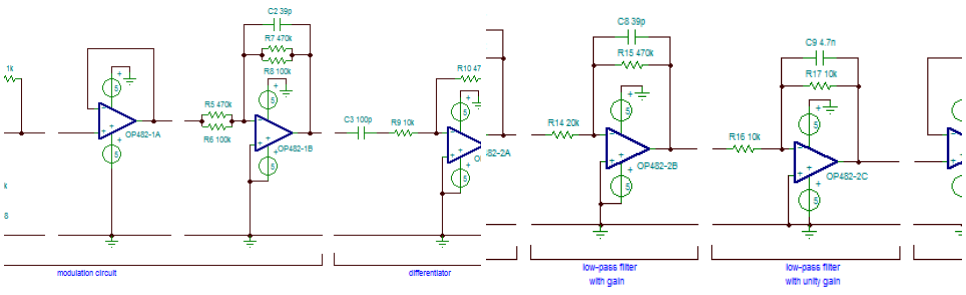
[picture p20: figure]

The schematic for this can be daunting to say the least. When I first started working with it, I got lost all the time and had to keep going back over it again and again. You'll notice in the schematic that there are breaks throughout the design. Each of those breaks represents a good stopping point for verifying the circuit function. Take it slow and add one section at a time. The OP482 ICs are quad op-amps, meaning four op-amps on one piece of silicone. That can make it tricky to hook everything together as components can get crowded. This project can be built using individual op-amps if that is easier for you, but I would recommend using the OP27 and not the LM741. The LM741 should work, but I have had problems with it when it comes to needing fast, reliable response times. The specs are just a bit too slow for some applications, specifically the skew rate when you need high gain at a relatively high frequency.

For clarification the schematic image is broken up. Point A matches to point A, B with B.

## Step 3: Frequency Modulation

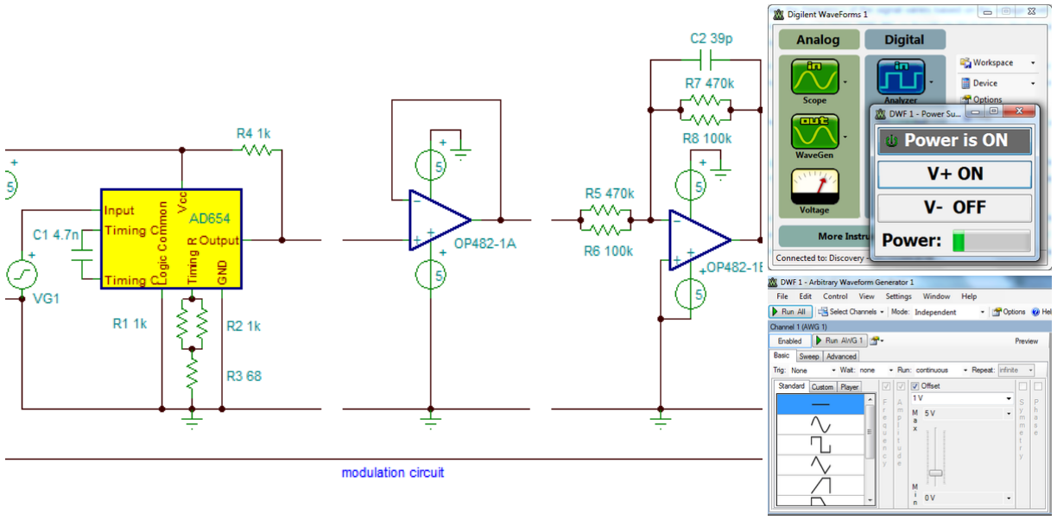
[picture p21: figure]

I won't go into the details of FM or AM technology too much here. I would refer you to Wikipedia (http://en.wikipedia.org/wiki/Frequency_modulation) for that (note the animation on the right side of the page). In a nutshell, for FM signals, the frequency of the signal varies based on the voltage level coming in. So a high voltage gives a high frequency, and vice versa. With AM, the frequency stays the same, but the amplitude goes high or low depending on the input voltage. As you will see, this circuit actually uses both.

The higher frequency signal is the carrier frequency, while the original signal is the data that you want to relay. We will use the data signal to modulate a much higher frequency carrier wave. Later we will filter out the carrier and recover the data.

The first three sections of the schematic are the modulation circuit. We first modulate the carrier wave, then amplify it. The AD654 changes the frequency of the output based on the voltage level of the input. The timing resistors and capacitors give a base frequency value for the IC to work with based on the equation found in the datasheet.

Using pages 1 and 4 of the datasheet (http://www.analog.com/static/imported-files/data_sheets/AD654.pdf) for the AD654, connect the components as shown. Note that 'Vs' indicates voltage supply, so '+Vs' is +5V and '-Vs' is ground. '+Vin' is the signal coming from the Analog Discovery AWG Channel 1 pin, labeled 'input' in the schematic.

Turn on the Voltage function from the Waveforms main window (image 2). Click V+ to 'ON', connect the red V+ wire from the Discovery header to pin 8 on the AD654, then turn it on. Using the Discovery's AWG channel 1, output a 1VDC signal (image 3) and plug it into pin 4 of the AD654. You should get a readout on the scope like image 4.

Next we add the first OP482. The first part is a simple voltage follower or buffer. (http://en.wikipedia.org/wiki/Voltage_follower) Since op-amps are active components, we will get a boost in current from this part. Next we add an active low-pass filter (http://en.wikipedia.org/wiki/Low-pass_filter) set to cutoff at approximately 50kHz, which is high enough to allow our signal to pass through but low enough to filter out random high frequency noise we don't want. When connecting the OP482, connect the Discovery's red V+ wire to pin 4 and the white V- wire to pin
11. Turn on the power supply (like in image 2, but both channels this time) before turning on AWG 1 with the signal. Set AWG 1 to an amplitude of 500mV this time. Your scope should look something image 5.

## Step 4: Differentiator and Envelope Detector

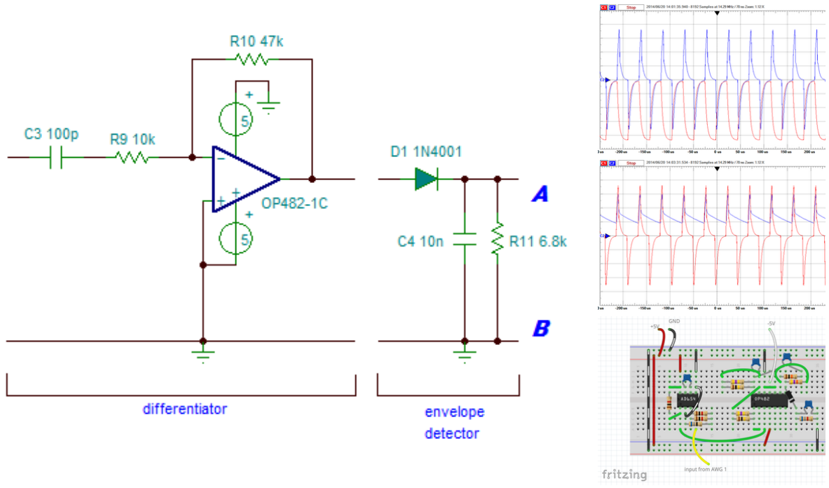
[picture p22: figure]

The theory behind most of these parts is a bit much to get into here. Again, check out wikipedia for the differentiator (http://en.wikipedia.org/wiki/Differentiator) (note that this one is active because of the op-amp) and the envelope detector explanations. In short, the differentiator, believe it or not, differentiates the signal (http://en.wikipedia.org/wiki/Envelope_detector) (think calculus and it makes total sense). As the input signal rises or falls quickly (high frequency), the output amplitude increases. As the input rises or falls slowly (low frequency), the output amplitude decreases closer to 0. This has the interesting effect of turning the FM signal into an AM signal. See the o-scope display in image 2 for a comparison (scope CH 1 to pin 14 of the OP482 and CH 2 to pin 8).

The envelope detector detects only the top edge of the signal, so as the amplitude rises and falls, so will the signal coming out of the envelope detector. See image 3 for an example (CH 1 to pin 8 of OP482 and CH 2 to cathode of 1N4001 diode).

## Step 5: Filtering

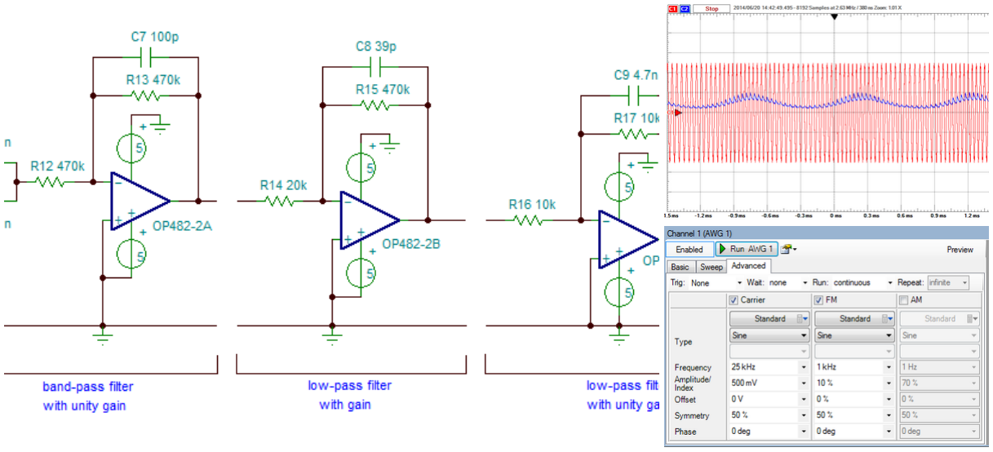
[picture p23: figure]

The signal from the envelope detector doesn't have much amplitude and contains quite a bit of noise. So we add several filters to both clarify and boost the signal. Look at the o-scope display in image 2. The red CH 1 signal is a 25kHz carrier with a 1kHz modulation frequency, amplitude of 500mV and index of 10%. These settings are all under the advanced tab on the Analog Discovery AWG tool (see image 3) if you would like to generate the signal yourself. This signal then is inserted into the input of the differentiator, bypassing the modulation circuit for now. The blue CH 2 is the output of the envelope detector, before any filtering. Do you see the scale on the left of the display in image 2? Each division is 20mV for CH 2. Most scopes will let you choose different scales for each channel, and here the scale for CH 1 is 200mV/div, larger by a factor of 10. With these two signals on a scale of 200mV/div, you would barely be able to see the output of the envelope detector because it is so weak. You can also see the noise in the signal as well in image 2. We need to filter that out and amplify the signal by a fair amount. We will also be running the signal through a band-pass filter to only allow audible frequencies between 200Hz and 2kHz to pass.

The first part is the band-pass filter. (http://en.wikipedia.org/wiki/Band-pass_filter) It allows only a small range of frequencies to pass through, and in our case 200Hz to 2kHz is more than enough. Note that because the resistors match, there is no gain here, only filtering. We don't want to amplify noise, so let's filter it out first.

After the band-pass filter we have two low-pass filters, (http://en.wikipedia.org/wiki/Low-pass_filter) the first with gain of approximately 23.5 and cutoff of about 8.6kHz, and the second with unity gain of 1, which means no amplification, and cutoff of about 3.4kHz. Even after the band-pass filter we still have some noise from the carrier wave (filters aren't perfect after all) and the signal is weak. We filter out noise above 8.6kHz and then amplify it 23.5 times. Yep, it's high but it needs it (you can change it by changing the resistor ratio. Click the low-pass filter link above for the equation). The second low-pass filter then further cleans up that signal by filtering noise above 3.4kHz, which is higher than our target range of 200Hz-2kHz, so we're good. The second filter is not absolutely necessary, but it did make a difference in the end.

Image 4 shows the difference in the signal between the output of the envelope detector and the output of the last filter. The scale is not exactly the same as before, but the data was just outside of range so I shrunk it down a little bit. Did you notice the measurement window at the bottom right? That's the 1kHz modulation value we saw in the settings in image 3 above. It's not a perfect sine wave, but it's a far sight cleaner than it was before, and it's good enough that you won't notice the difference.

If you don't want to add the class B amplifier, you're done here. Otherwise, get yourself some 9V batteries and turn the page.

## Step 6: Amplifying the Signal

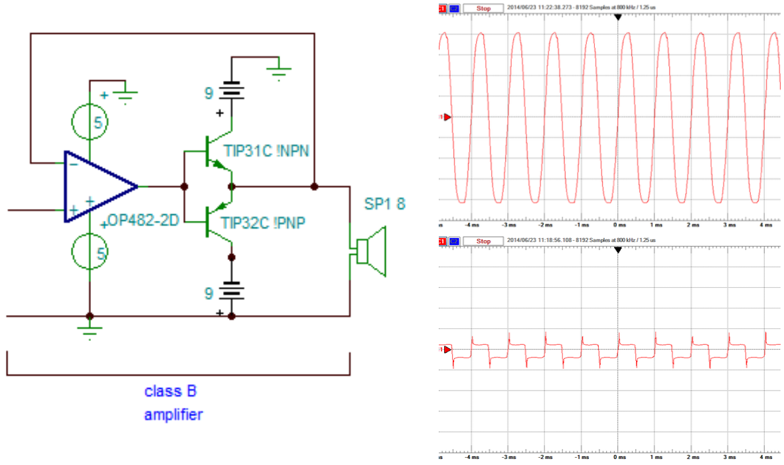
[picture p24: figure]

The 9 V batteries and connectors are not included with the Analog Parts Kit, and it is not absolutely necessary to amplify the signal coming from the last low-pass filter. However, as you can see from comparing images 2 and 3, the signal will clip when you add the speaker and form more of a square wave than a sine wave. A small 8-Ohm speaker will clip even more. This happens because the speaker itself also has a transfer function that must be accounted for, which is a fancy way of saying that it is trying to draw too much current at peak voltage, so it clips the voltage. It will actually sound louder, but won't be as clear. Adding the amplifier allows more current to be available and that allows the voltage level at the speaker match the output level at the last filter. Image 4 shows the signal with the amplifier in place and the speaker attached. The difference is minimal this time. I've used this on a 4-inch computer speaker I salvaged and even a 6-inch woofer and they all worked with this amplifier. Just remember that larger speakers require more current so you will drain your batteries faster.

When putting the BJTs on the breadboard it is very easy to get the pins mixed up. I've built this circuit, start to finish, at least half a dozen times, and I still did it. Again. I've included the pin-out diagram for them (they have the same B/C/E pin assignments), so good luck.

## Step 7: Testing

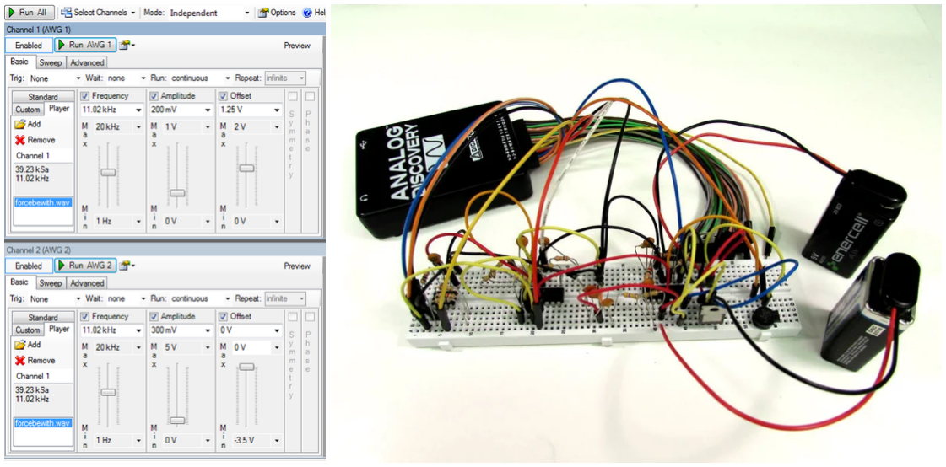
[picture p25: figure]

Now let's do some testing to verify. If you haven't yet downloaded a short .wav file, (http://www.wavsource.com/) do so now. Go into the AWG tool settings and check both channels to turn them both on. Click on the 'player' tab, then on 'add'. A window will come up to allow you to find the downloaded .wav file. Double click on it to load it. Notice the playback frequency in the window to the left? My file is set at 11.02kHz. For now, set the AWG channels to playback at this frequency. You won't break anything if you change it, it just changes the playback speed of the file. Load the file for both AWG channels. There are notes on the image that will help clarify this step.

Set the channels according to image 1, making sure that the offset for CH 1 is 1.25V. It will make a big difference and took me a while to troubleshoot the first time. The amplitude (volume) settings are not super critical, but remember that we are amplifying the signal by quite a lot in the circuit, so start smaller and work your way up as desired.

Start with CH 2 on the AWG and plug the yellow/white wire directly into the speaker, bypassing the entire circuit. This way you can hear the file playback on the speaker before passing it through the circuit. Once you have it playing on the speaker using CH 2, plug CH 1 into pin 4 of the AD654. Unplug AWG CH 2 from the speaker and connect the output of the class B amplifier to the speaker. You should hear the same playback either way.

And there you have it. Please don't hesitate to ask questions, either in the comments below or PM. Have fun building!

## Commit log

2026-04-16 Added report and kicad fm-vco
    [FM-Spannungsversorgung.kicad_sch, FM-Treiber.kicad_sch, FM-VCO.kicad_pcb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]
2026-04-16 Add updated project files
    [ANS_Uebung1.kicad_pcb, ANS_Uebung1.kicad_sch, ANS_Uebung1_kicad.csv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]
2026-05-07 Laborübungen und Dokumentation hinzugefügt
    [ANS_Uebung1.kicad_pcb, ANS_Uebung1.kicad_sch, ANS_Uebung1_kicad.csv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]
2026-05-21 Added varactor diodes
2026-06-03 VCO 03.03.26
    [ANS_Uebung3.kicad_sch, CC_VCO.kicad_pcb, CC_VCO.kicad_sch]
2026-06-03 CC-VCO Schematic und Quarto doku angepasst
    [CC_VCO.kicad_sch]
2026-06-10 Bericht angepasst
    [CC_VCO.kicad_sch]
2026-06-10 Platine erstellt
    [CC_VCO.kicad_sch]
2026-06-11 Platine aktualisiert
    [CC_VCO.kicad_pcb, CC_VCO.kicad_sch]
2026-06-11 Schematic update
    [CC_VCO.kicad_sch]
2026-07-02 Added simple LC-VCO BS170
    [FM-ELK.kicad_pcb, FM-ELK.kicad_sch]
2026-07-17 Bauteilwerte angepasst und lib hinzugefügt
    [FM-ELK.kicad_sch]
2026-07-17 Projekt aktualisiert
    [ANS_Uebung1.kicad_pcb, ANS_Uebung1.kicad_sch, ANS_Uebung1_kicad.csv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]
2026-07-18 Readme angepasst und images hinzugefügt
2026-07-18 Python auswertung und readme aktualisiert
    [F0005CH1.CSV, F0006CH1.CSV, F0007CH1.CSV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]
2026-07-18 Board aktualisiert und Python angepasst
    [FM-ELK.kicad_pcb, FM-ELK.kicad_sch]
2026-07-19 readme und auswertung angepasst
2026-07-19 Ubenannt udn alte dateinen hinzugefügt
    [FM-ELK.kicad_pcb, FM-ELK.kicad_sch, LC VCO.kicad_pcb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]
2026-07-19 Aktuelle Version hochgeladen
    [FM-ELK.kicad_sch, LC VCO.kicad_sch]
2026-07-20 Kommentare hinzugefügt
    [FM-ANS_LC-VCO-V4.kicad_pcb, FM-ANS_LC-VCO-V4.kicad_sch, FM-EL_V4.kicad_sch]
